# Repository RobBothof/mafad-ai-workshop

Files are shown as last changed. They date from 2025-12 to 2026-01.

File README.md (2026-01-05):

# KABK x MAFAD - AI hardware workshop

**by Rob Bothof (2026)**

---

## Synopsis

In this workshop students explore Machine Learning (ML) in a hardware-oriented context. We build insect-like robots that perform and respond to birdsong like, digital signature sounds and melodies, designed by student.

The workshop aims to debunk myths around Artificial Intelligence by focussing on fundamental / low-level neural networks that can run on a stand-alone microcontroller, free from the cloud. Students design signature sounds and create a robust dataset for neural network classification. We train and demploy the neural network model to create non-linear mappings between sensor inputs and hardware outputs.

The trained neural network model can listen to melodies of other machines in the flock. Students develop their own strategies / tactics on how their machine responds to others with the machine’s outputs (lights / speaker). By tuning and training the models on custom training data, and developing strategies for response, the end goal is to create an emergent behavioural performance from these machines as they react to each other as a group, herd, or small swarm.

---

## Subjects

- Primer on Machine Learning
- Basic soldering of electronics
- Deploy code to test sensors en outputs
- Code digital birdsong like signature sounds and melodies
- Experiment with model training and datasets
- Deploy and test a neural network model on embedded hardware
- Develop communication strategies
- Experiment and create a collaborative performance / installation

---

## Hardware Guide

[hardware/kabk_ai_workshop_hardware_guide.pdf](hardware/kabk_ai_workshop_hardware_guide.pdf)

---

## AI Primer

[primer/kabk_ai_workshop_primer.pdf](primer/kabk_ai_workshop_primer.pdf)

---

## Edge Impulse Project

[https://studio.edgeimpulse.com/public/869270/live](https://studio.edgeimpulse.com/public/869270/live)

---

## Requirements

### Hardware
- Workshop kit (PCB, electronics, UM Feather S3 board)
- Micro SD Card

### Software
- Laptop (with usb-A port)
- Arduino IDE [https://www.arduino.cc/en/software/](https://www.arduino.cc/en/software/)

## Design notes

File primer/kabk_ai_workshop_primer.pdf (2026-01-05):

Artificial Intelligence (AI)
A field and practice focused on building computational systems that perform tasks linked to human intelligence, such as recognizing patterns, creating content, or making decisions. The term is also used loosely to describe specific systems or tools that seem intelligent. Today it is most often used as a buzzword in presentations or sales pitches.

Artificial General Intelligence (AGI)
A hypothetical type of AI that could understand, learn, and perform any intellectual task a human can. Unlike current AI, which is specialized and task-specific, AGI would be flexible and adaptable across domains. Science Fiction.

Machine Learning (ML)
Machine Learning is the academic and practical discipline focused on designing systems (algorithms / models) that can ‘learn’ from data / examples and then apply that knowledge to new material.

Learning
Iterative process of automated adjustment of a system’s internal parameters, where the system’s performance is constantly monitored and influences the the adjustments for the next iteration. See also: Training (A Neural Network specific learning method)

Neural Network
A popular and powerful design architecture within Machine Learning, inspired by the structure of the human brain. It serves as the general architecture for a data model, where different types/designs of Neural Networks can perform different functions. (e.g. recognise, generate, predict). A neural network can be shallow (few layers) or deep (many layers). It is composed composed of layers of connected “neurons”

Model
The actual data structure that is being trained and used to make predictions. The term ‘model’ is easily misunderstood, we would think of a ‘model’ as being a design or a blueprint, but this term is somewhat counterintuitive. The model is a specific instance of a neural network, containing the exact layout of neurons, connections, layers and the weights (and biases) used in each neuron. A model is essentially a structured collection of numbers, comparable to a database.

Neuron
A computational unit that receives multiple input values from neurons in the previous layer and produces a single output value. Each incoming value is scaled by a weight associated with the connection it arrives on. The neuron combines these weighted inputs, applies a simple transformation, and forwards the resulting output value to connected neurons in the next layer.

Training
The process of adjusting a neural network model’s weights using a dataset of examples. Initially, all the model’s parameters (weights) are set to random values. The training process then iteratively evaluates whether changes to the weights improve or worsen how well the model matches the examples, and adjusts the weights accordingly, for example keeping, increasing, or slightly decreasing the values in preparation of the next iteration.

Loss
Measurement tool. A number used during training to show how well the model’s outputs match the examples. High loss means the model is doing poorly; lower numbers mean it’s doing better. The training process aims to reduce this number over time.

Validation
During training, the model is also tested on data it has not seen yet (similar examples, but ones are not part of the training set). This helps to determine whether the model can generalize to new data or if it has simply memorized the training examples.

Inference
Where training is very resource- and time-intensive and usually happens only once (or occasionally for updates), Inference is the common use case for a neural network model. Inference is using a model to produce an actual result. For example: classifying an image, generating text, or predicting a value. Inference is fast and lightweight compared to training.

Layer
A layer is a group of neurons in a neural network that process data together. Neural Network usually consist of multiple layers stacked on top of each other. Lower layers (closer to the input) typically capture simple features (like edges in images or individual characters or words in text), while higher layers capture more complex or abstract features (like objects such as “cat” or “face” in images, or meaning, sentiment, or topic in text). There are many different types of layers and architectures.

– Dense Layer, Fully connected layer, basic building block (weight, bias, activation function)
– CNN, Convolutional layer, local connections only, shared weights, used for images / audio
– RNN / LSTM, Recurrent layer, uses feedback, designed for sequential data (obsolete)
– Attention / Transformer, uses weighted relationships across a data-sequence, backbone modern language and audio models, used for classification and generation

– GANs, Generative Adversarial Networks, used for images generation and style transfer (obsolete) – Diffusion models, current state of the art, image, audio, and video generation, Generate data by gradually removing noise
– Autoregressive Transformers, generate data step-by-step, text, music, and audio synthesis

Weight
A weight is a number assigned to a connection between two neurons that controls how strongly the output of one neuron influences the input of the next. Weights scale incoming values before they are combined inside a neuron. During training, these weights are adjusted to strengthen useful connections and weaken unhelpful ones.

Bias
Similar to a weight, the bias is a parameter that can be changed/optimized during the training process. But where weights are stored for each connection between neurons, each neuron has their own bias value and that value is added to the sum of the values from incoming connections. It can be seen as a baseline,offset or tunable starting value for a neural. The bias gives a neural more agency or freedom to react independently from the values it receives on its inputs.
Artificial Intelligence / Machine Learning Primer ( 1 / 3 ) | version 1.0 - Rob Bothof - 2025

Activation function
An activation function is a transformation that is applied inside a neuron (after the weighted inputs and bias are combined) that shapes its output signal. It acts like a nonlinear gain or dynamics stage, controlling how strongly a neuron responds to its inputs. Neurons are not literally turned on or off; they always produce an output value, but an output close to zero is often described as the neuron being “inactive.”

Deep Learning
A subset of Machine Learning that uses ‘deep’ neural networks with many layers to learn complex patterns from data. Deep Learning models are typically more powerful than shallow networks but require more data and computational resources. It is the technique behind many modern AI applications, like image recognition and large language models.

LLM (Large Language Model)
A type of deep learning model trained on massive amounts of text to understand and generate human-like language. LLMs can perform tasks like answering questions, summarizing text, translating languages, or generating content, and rely on complex neural network architectures with billions of parameters.

Transformer
A neural network architecture designed for processing sequences of data, such as text. Transformers use mechanisms called attention to weigh the importance of different parts of the input, allowing them to capture long-range dependencies efficiently. They are the backbone of modern large language models and many state-of-the-art AI systems.

Fine-Tuning
The process of taking a pre-trained base model and continuing training on a smaller, specific dataset to adapt it to a particular task or domain. This is a popular contemporary method or creating a model. It allows one to create specialized models without the need to train an entire model from scratch.Models can be fine tunes with less cost and with simpler hardware or without the need to collect large datasets. Commonly the weights of the lower layers of a model are left locked and only the higher layers are retrained. In some cases additional layers are added on top of the base layer.

Hyperparameters
Hyperparameters are user-defined settings that control how a model is trained, not the model’s structure itself. They determine learning speed, training duration, and constraints on learning behavior. Hyperparameters are typically adjusted through experimentation and evaluated using validation data.

Classifier
A classifier is a type of AI or machine learning model that assigns an input to one of a predefined set of categories (classes) based on learned patterns in the data.

Label
A label is the class or category assigned to a data example. Labels define the set of possible outcomes a model can predict and are chosen and applied by the developer. In image/object classification, labels might include categories such as dog, cat, or bicycle.

Feature
A feature is an individual, measurable piece of information used as input to a machine learning model. Feature extraction is a preparation process to transform the data into something that is more usable in a machine learning context. Features describe characteristics of the data that the model uses to learn patterns and make predictions. For example when classifying sound, a feature is usually based on spectral content — which frequencies are present and how they change over time, not the raw audio data.

Dataset
A dataset is a structured collection of data examples used to train, tune, and evaluate an AI or machine learning model.
– Training set
Purpose: Teach the model
Used to adjust the model’s internal parameters
– Validation set
Purpose: Tune the model
Used during development to: Estimate the quality of a model, compare models, decide when to stop training. The model does not learn directly from this data – Test set
Purpose: Evaluate final performance using unseen examples of the data

Overfitting
Overfitting occurs when a model learns the training data too exact. It only memorizes the dataset exactly but is unable to generalize on characteristics and as a result performs poorly on new, unseen data. The most common causes for this are: Too little and unvaried data, the training data does not reflect real-world conditions, bad data preparation or mislabeling.
Artificial Intelligence / Machine Learning Primer ( 2 / 3 ) | version 1.0 - Rob Bothof - 2025

Artificial Intelligence / Machine Learning Primer ( 3 / 3 ) | version 1.0 - Rob Bothof - 2025

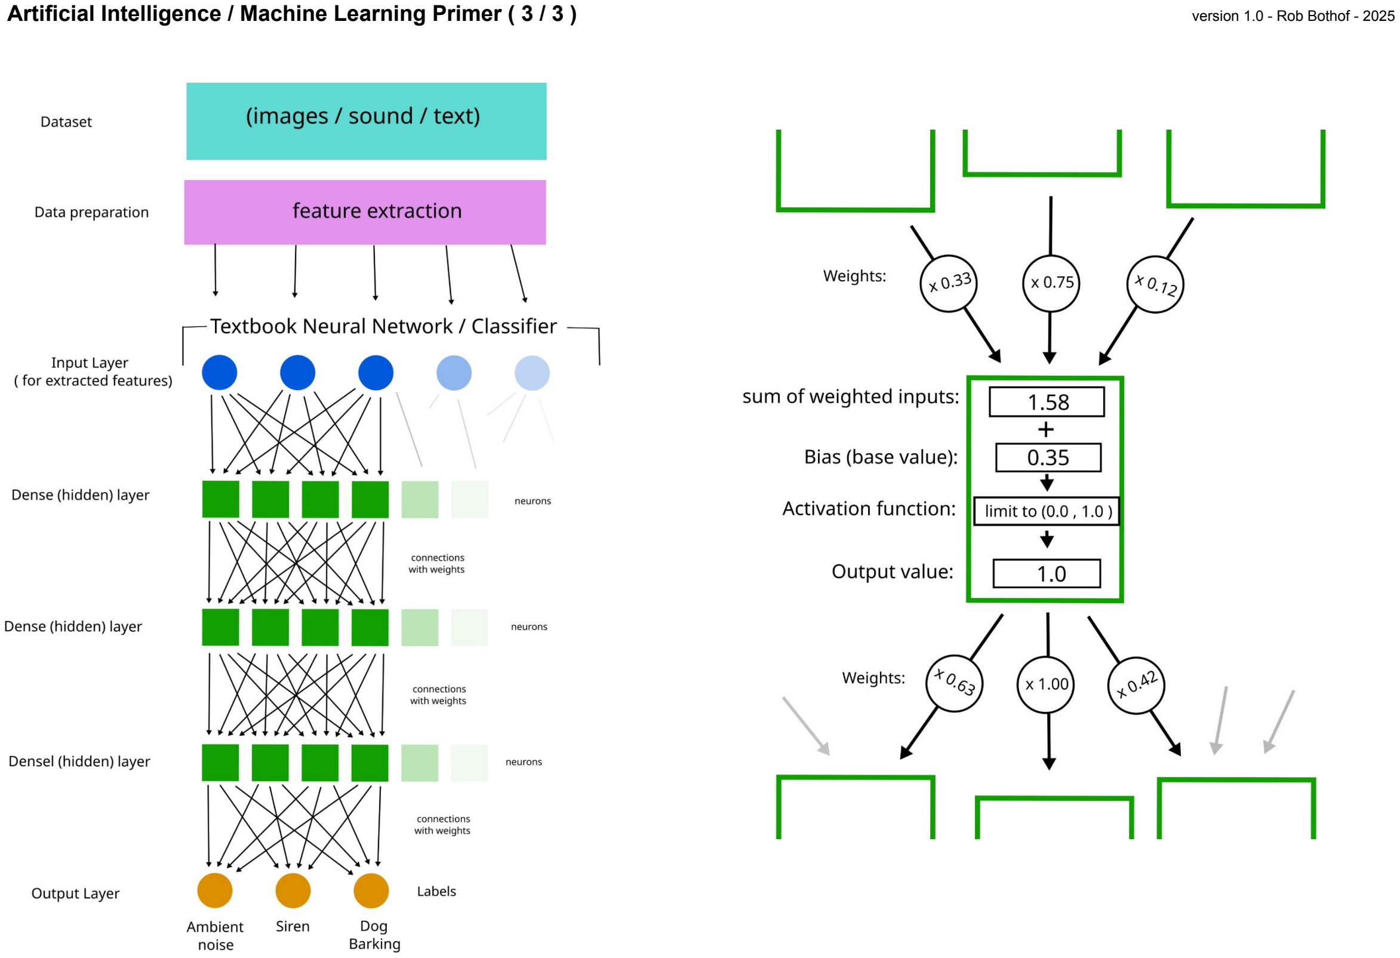
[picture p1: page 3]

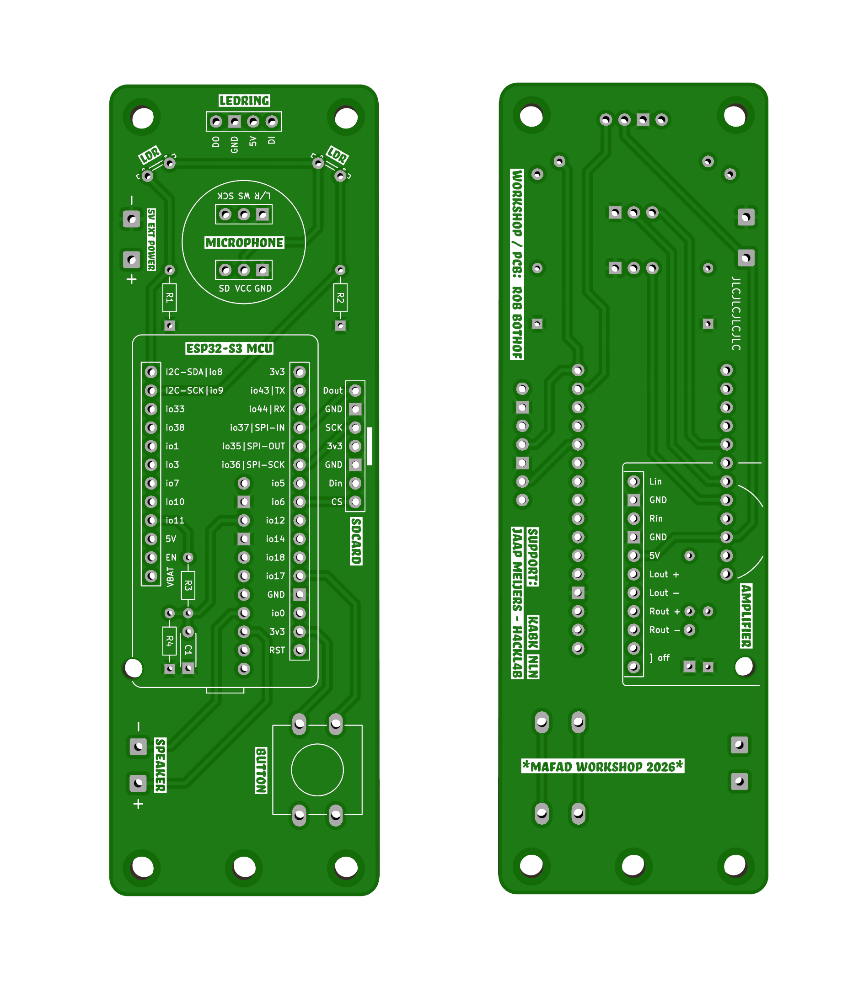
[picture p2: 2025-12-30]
hardware/PCB/MAFAD-Workshop.png

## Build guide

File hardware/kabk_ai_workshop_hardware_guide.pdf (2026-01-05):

KABK Workshop AI Hardware guide ( 1 / 1 ) | version 1.0 - Rob Bothof - 2025

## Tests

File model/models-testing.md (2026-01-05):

========================

ei-mafad-classifier-arduino-1.0.5.zip

Cropped
all classes
Window size: 1000ms
Stride: 500ms

Frame length: 0.025
Frame stride: 0.01
Filter number: 41
FFT length: 512
Low frequency: 80
High frequency: 8000
Noise floor (dB): -75

epoch: 100
learning rate: 0.05
CPU
validation size: 20%

validation:
Accuracy: 94%
Loss: 0.15

test:
Accuracy: 91.94%

hello there: ***--
ilovecake:   ***--
get bonus:   ***--
random:      ***--

distance     *----
soft-close   *----

========================

ei-mafad-classifier-arduino-1.0.8.zip

Cropped
excluded random class
Window size: 1000ms
Stride: 500ms

Frame length: 0.01
Frame stride: 0.005
Filter number: 40
FFT length: 512
Low frequency: 80
High frequency: 8000
Noise floor (dB): -50

epoch: 40
learning rate: 0.02
CPU
validation size: 20%

validation:
Accuracy: 99%
Loss: 0.04

test:
Accuracy: 99.19%

mobile performance: **---
esp32 performance:  

========================

ei-mafad-classifier-arduino-1.0.13.zip

Cropped
all classes
Window size: 1000ms
Stride: 500ms

Frame length: 0.01
Frame stride: 0.005
Filter number: 40
FFT length: 512
Low frequency: 80
High frequency: 8000
Noise floor (dB): -50

epoch: 70
learning rate: 0.02
CPU
validation size: 20%

validation:
Accuracy: 99.2%
Loss: 0.04

test:
Accuracy: 99.03%

hello there: **---
ilovecake:   ****-
get bonus:   ***--  
random:      ****-

========================

ei-mafad-classifier-arduino-1.0.22.zip
Cropped
excluded random class
Window size: 1000ms
Stride: 500ms

Frame length: 0.01
Frame stride: 0.005
Filter number: 40
FFT length: 512
Low frequency: 300
High frequency: 8000
Noise floor (dB): -65

epoch: 50
learning rate: 0.02
CPU
validation size: 20%

validation:
Accuracy: 99.0%
Loss: 0.06

test:
Accuracy: 97.58%

hello there: *----
ilovecake:   ****-
get bonus:   ***--  
random:      -----

hello there performs worse at low volume somehow

========================

ei-mafad-classifier-arduino-1.0.14.zip

Master
all classes
Window size: 1000ms
Stride: 100ms

Frame length: 0.01
Frame stride: 0.005
Filter number: 40
FFT length: 512
Low frequency: 300
High frequency: 8000
Noise floor (dB): -60

epoch: 40
learning rate: 0.02
CPU
validation size: 20%

validation:
Accuracy: 99.4%
Loss: 0.02

test:
Accuracy: 95.97%

hello there: ***__
ilovecake:   ****_
get bonus:   ****_ 
random:      ****_

========================

ei-mafad-classifier-arduino-1.0.16.zip
Master
all classes
Window size: 1000ms
Stride: 200ms

Frame length: 0.01
Frame stride: 0.005
Filter number: 40
FFT length: 512
Low frequency: 300
High frequency: 8000
Noise floor (dB): -60

epoch: 40
learning rate: 0.02
CPU
validation size: 20%

validation:
Accuracy: 98.8%
Loss: 0.06

test:
Accuracy: 93.51%

hello there: *----
ilovecake:   **---
get bonus:   -----  
random:      ***--

========================
ei-mafad-classifier-arduino-1.0.18.zip

Master
excluded random class
Window size: 1000ms
Stride: 200ms

Frame length: 0.01
Frame stride: 0.005
Filter number: 40
FFT length: 512
Low frequency: 300
High frequency: 8000
Noise floor (dB): -60

epoch: 40
learning rate: 0.02
CPU
validation size: 20%

validation:
Accuracy: 100%
Loss: 0.05

test:
Accuracy: 97.75%

mobile performance: ***--
esp32 performance:  

======================================

ei-mafad-improved-classifier-arduino-1.0.3.zip

Architecture changes

Model:

- Input layer (7,960 features)
- Reshape layer (40 columns)
- 2D conv / pool layer (8 filters, 3 kernel size, 1 layer)
- Dropout (rate 0.2)
- 2D conv / pool layer (16 filters, 3 kernel size, 1 layer)
- Flatten layer
- Output layer (4 classes)

Master
all classes
Window size: 1000ms
Stride: 200ms

Frame length: 0.01
Frame stride: 0.005
Filter number: 40
FFT length: 512
Low frequency: 300
High frequency: 8000
Noise floor (dB): -65

epoch: 14
learning rate: 0.02
CPU
validation size: 20%

validation:
Accuracy: 99.2%
Loss: 0.05

test:
Accuracy: 94.56%

hello there: **---
get bonus:   ***--  
ilovecake:   ***--
random:      ****-

======================================

BEST MODEL:

ei-mafad-improved-classifier-arduino-1.0.5

Architecture changes

Model:

- Input layer (7,960 features)
- Reshape layer (40 columns)
- 2D conv / pool layer (6 filters, 5 kernel size, 1 layer)
- Dropout (rate 0.2)
- 2D conv / pool layer (12 filters, 3 kernel size, 1 layer)
- Flatten layer
- Output layer (4 classes)

Master
no random class
Window size: 1000ms
Stride: 200ms

Frame length: 0.01
Frame stride: 0.005
Filter number: 40
FFT length: 512
Low frequency: 300
High frequency: 8000
Noise floor (dB): -65

epoch: 15
learning rate: 0.02
CPU
validation size: 20%

validation:
Accuracy: 99.0%
Loss: 0.05

test:
Accuracy: 97.72%

hello there:    ****-
get bonus:      ****-    
ilovecake:      ***--
random:         -----

softer sounds  ****_
long distance   ***__
======================================

ei-mafad-improved-classifier-arduino-1.0.7
Architecture changes

Model:

- Input layer (7,960 features)
- Reshape layer (40 columns)
- 2D conv / pool layer (6 filters, 5 kernel size, 1 layer)
- Dropout (rate 0.2)
- 2D conv / pool layer (12 filters, 3 kernel size, 1 layer)
- Flatten layer
- Output layer (4 classes)

Master
all classes
Window size: 1000ms
Stride: 50ms

Frame length: 0.01
Frame stride: 0.005
Filter number: 40
FFT length: 256
Low frequency: 300
High frequency: 8000
Noise floor (dB): -40

epoch: 10
learning rate: 0.02
CPU
validation size: 20%

validation:
Accuracy: 98.4%
Loss: 0.06

test:
Accuracy: 98.41%

hello there: **---
ilovecake:   ***--
get bonus:   ****-    
random:      ****-

softer sounds **---
long distance **---

============================================================================
ei-mafad-improved-classifier-arduino-1.0.9.zip

Architecture changes

Model:

- Input layer (7,960 features)
- Reshape layer (40 columns)
- 2D conv / pool layer (6 filters, 5 kernel size, 1 layer)
- Dropout (rate 0.2)
- 2D conv / pool layer (12 filters, 3 kernel size, 1 layer)
- Flatten layer
- Output layer (4 classes)

Manual Crops
all classes
Window size: 1000ms
Stride: 200ms

Frame length: 0.02
Frame stride: 0.015
Filter number: 30
FFT length: 128
Low frequency: 300
High frequency: 8000
Noise floor (dB): -40

epoch: 20
learning rate: 0.02
CPU
validation size: 20%

validation:
Accuracy: 94.55%
Loss: 0.15

test:
Accuracy: 94.55%

hello there: ***--
ilovecake:   ***--
get bonus:   *----
random:      ****-

======================================
======================================

======================================
======================================
======================================
======================================
New dataset (but hello_there only had 1/2 samples)
======================================
ei-mafad-classifier-arduino-1.0.23.zip

Model:

- Input layer (7,960 features)
- Reshape layer (40 columns)
- 2D conv / pool layer (8 filters, 5 kernel size, 1 layer)
- Dropout (rate 0.2)
- 2D conv / pool layer (16 filters, 3 kernel size, 1 layer)
- Flatten layer
- Output layer (4 classes)

Master Files
all classews
Window size: 1000ms
Stride: 200ms

Frame length: 0.01
Frame stride: 0.005
Filter number: 40
FFT length: 512
Low frequency: 200
High frequency: 7000
Noise floor (dB): -75

epoch: 15
learning rate: 0.02
CPU
validation size: 20%

validation:
Accuracy: 85.3%
for melody labels: 100%
Loss: 0.4

test:
Accuracy: 76.96%
for melody labels: 98%

hello there: -----
ilovecake:   -----
get bonus:   -----
random:      -----

=====================================
======================================
ei-mafad-classifier-arduino-1.0.25.zip

Model:

- Input layer (7,960 features)
- Reshape layer (40 columns)
- 2D conv / pool layer (8 filters, 5 kernel size, 1 layer)
- Dropout (rate 0.2)
- 2D conv / pool layer (16 filters, 3 kernel size, 1 layer)
- Flatten layer
- Output layer (4 classes)

Master Files
(noise + random combined)
Window size: 1000ms
Stride: 200ms

Frame length: 0.01
Frame stride: 0.005
Filter number: 40
FFT length: 512
Low frequency: 200
High frequency: 7000
Noise floor (dB): -75

epoch: 15
learning rate: 0.02
CPU
validation size: 20%

validation:
Accuracy: 97.2%
Loss: 0.07

test:
Accuracy: 95.49%

hello there: ***--
ilovecake:   *****
get bonus:   *****
noise:       *****

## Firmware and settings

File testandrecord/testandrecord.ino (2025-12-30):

#include <Bounce2.h>
#include "workshop/WS2812.h"
#include "workshop/workshop_library.h"
#include "workshop/pitches.h"

#define I2S_MIC_SCK_PIN 1         // clockPin
#define I2S_MIC_WS_PIN 7          // wordSelectPin
#define I2S_MIC_SD_PIN 10         // channelSelectPin

#define SDCARD_CS_PIN 6           // sdcard chip select pin

#define AUDIO_OUT_PIN 11          // amplifier / speaker pin
#define BUTTON_PIN 17             // button pin
#define LEDRING_PIN 43            // ledring data pin

#define LDR_LEFT_PIN 8            // left lightsensor pin
#define LDR_RIGHT_PIN 9           // right lightsensor pin

#define SAMPLE_RATE 20000         // recording quality 20khz (20.000 samples per second)
#define SAMPLE_BUFFER_SIZE 40000  // size of the audio buffer, 2 seconds ( 2 * 20.000 = 40000 samples)

#define NUM_LEDS 8                // the ledring uses 8 leds


// Create an array/list to store 8 colors for the ledring.
Color leds[NUM_LEDS];       
int activeLed = 0;

// Create a button object (with debouncing).
Bounce2::Button Button1 = Bounce2::Button();

// Create a led ring object.
WS2812 ledRing;

// Create a sd card object.
SDCard sdCard;

// Create a microphone object.
i2sMic microphone;

// Define a series of notes. (Cminor chord)
int melody[] = { NOTE_C3, NOTE_D3, NOTE_DS3, NOTE_F3, NOTE_G3, NOTE_GS3, NOTE_AS3, NOTE_C4};

// Create a 32bits buffer to store audio.
int32_t audioBuffer[SAMPLE_BUFFER_SIZE]; 

// Create a boolean to remember if an sd card is present.
bool hasSDCard = false;

// Create a value to keep track of elapsed time.
unsigned long log_timer=0;

// Create a value to keep track of the recordings we store
unsigned int fileIndex=0;

// Create a series of notes.
int notes[] = {
  NOTE_C2, NOTE_CS2, NOTE_D2, NOTE_DS2, NOTE_E2, NOTE_F2, NOTE_FS2, NOTE_G2, NOTE_GS2, NOTE_A2, NOTE_AS2, NOTE_B2,
  NOTE_C3, NOTE_CS3, NOTE_D3, NOTE_DS3, NOTE_E3, NOTE_F3, NOTE_FS3, NOTE_G3, NOTE_GS3, NOTE_A3, NOTE_AS3, NOTE_B3,
  NOTE_C4, NOTE_CS4, NOTE_D4, NOTE_DS4, NOTE_E4, NOTE_F4, NOTE_FS4, NOTE_G4, NOTE_GS4, NOTE_A4, NOTE_AS4, NOTE_B4,
  NOTE_C5, NOTE_CS5, NOTE_D5, NOTE_DS5, NOTE_E5, NOTE_F5, NOTE_FS5, NOTE_G5, NOTE_GS5, NOTE_A5, NOTE_AS5, NOTE_B5,
  NOTE_C6
};




void setup(){

  // Setup LightSensors
  pinMode(LDR_LEFT_PIN,INPUT);
  pinMode(LDR_RIGHT_PIN,INPUT);

  // Setup LedRing
  pinMode(LEDRING_PIN, OUTPUT);
  ledRing.init(LEDRING_PIN, leds, NUM_LEDS);

  // Turn all leds off
  for (int l=0; l < NUM_LEDS; l++) {
    leds[l].hex = 0x000000;
  }
  ledRing.update();

  // Setup microphone
  microphone.setup(SAMPLE_RATE, I2S_MIC_SCK_PIN, I2S_MIC_WS_PIN, I2S_MIC_SD_PIN);

  // Setup printing to serial monitor
  Serial.begin(115200);
  Serial.println("\n--------------------");

  // Set up Button
  Button1.attach(BUTTON_PIN, INPUT_PULLDOWN);
  // Set debounce time
  Button1.interval(10);
  Button1.setPressedState(HIGH); 

  // Setup audio output
  pinMode(AUDIO_OUT_PIN, OUTPUT);
  analogWriteResolution(AUDIO_OUT_PIN, 10);

  // Try to mount the SD Card and remember if it is present
  hasSDCard = sdCard.setup(SDCARD_CS_PIN);

  delay(1000);

  // Play 8 notes and light up 8 LEDs
  for (int index = 0; index < 8; index++) {

    // Set the LED corressponding with to a random color (random Hue)
    leds[index] = Color::FromHSL(random(255),255,128);
    // Write the led values to the ledRing.
    ledRing.update();

    // set the corresponding frequency of the note.
    analogWriteFrequency(AUDIO_OUT_PIN, melody[index]);

    // Sound on.
    analogWrite(AUDIO_OUT_PIN, 512);

    // Wait 1/2 second.
    delay(500);

    // Sound on.
    analogWrite(AUDIO_OUT_PIN, 0);

    // Set all leds to off
    for (int l = 0; l < NUM_LEDS; l++) {
      leds[l].hex = 0x000000;
    }
    // Write the led values to the ledRing.
    ledRing.update();

    // Wait 1/5 seconds.
    delay(200);

  }

  Serial.println();
  Serial.println("Press button to record a test sample");
  Serial.println();

  // prime the timer (set it to current time)
  log_timer = millis();
}

void loop(){
  Button1.update();

  if(Button1.pressed()) {  // Returns true if the button was pressed

      // wait 1/5 of a second before starting with recording
      delay(200); 
      Serial.println("Now recording 2 seconds..");

      int numSamplesRecorded = microphone.record(audioBuffer, SAMPLE_BUFFER_SIZE);
  
      Serial.print("samples recorded:");
      Serial.println(numSamplesRecorded);
      Serial.println();

      // save the recorded audio to the SDCard (if present)
      if (hasSDCard) {
        // Create a filename with the format: /recording_0001.wav 
        String filename = sdCard.makeFilename("/recording", fileIndex);

        // Increase the file index with 1
        fileIndex++;

        Serial.print("Saving on SDCard as:");
        Serial.println(filename);
        Serial.println();

        sdCard.writeWavFile(filename, audioBuffer, numSamplesRecorded, SAMPLE_RATE);
      }      
  } 

  // Print the values of the lightsensors every second.
  // this prevents the values being logged continuously, stalling the device
  if (millis() > log_timer + 1000) {
    // set our timer to the current time.
    log_timer = millis();
    Serial.print("Light Sensor L:");
    Serial.print(analogRead(LDR_LEFT_PIN));
    Serial.print(" | Light Sensor R:");
    Serial.println(analogRead(LDR_RIGHT_PIN));
  }


}

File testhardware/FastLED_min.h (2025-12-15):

/*
 * WS2812_ARRAY - WS2812B Library for ESP32S3 (CORE >= v3) using RMT
 * 
 * Supports: WS2812B, WS2812, WS2811 compatible LEDs
 *
 * Rob Bothof [rbothof@xs4all.nl]
 */

#ifndef WS2812_ARRAY
#define WS2812_ARRAY

#include <Arduino.h>

class Color {
public:
  union {
    struct {
      uint8_t b;
      uint8_t r;
      uint8_t g;
      uint8_t x; // 8 bit spacer so we can map hex values like 0xFF00FF to r,g,b
    };
    uint32_t hex;
  };
  
  // Constructors
  Color() : r(0), g(0), b(0) {}
  Color(uint8_t red, uint8_t green, uint8_t blue) : x(0), r(red), g(green), b(blue) {}
  Color(uint32_t rawvalue) : hex(rawvalue) {}
  
  // Named colors
  static const Color Black;
  static const Color Red;
  static const Color Green;
  static const Color Blue;
  static const Color Yellow;
  static const Color Cyan;
  static const Color Magenta;
  static const Color White;
  static const Color Orange;
  static const Color Purple;
  static const Color Pink;
  
  // Copy Operator
  Color& operator=(const Color& other) {
    x = 0;
    r = other.r;
    g = other.g;
    b = other.b;
    return *this;
  }
};

// Define named colors
inline const Color Color::Black = Color(0, 0, 0);
inline const Color Color::Red = Color(255, 0, 0);
inline const Color Color::Green = Color(0, 255, 0);
inline const Color Color::Blue = Color(0, 0, 255);
inline const Color Color::Yellow = Color(255, 255, 0);
inline const Color Color::Cyan = Color(0, 255, 255);
inline const Color Color::Magenta = Color(255, 0, 255);
inline const Color Color::White = Color(255, 255, 255);
inline const Color Color::Orange = Color(255, 165, 0);
inline const Color Color::Purple = Color(128, 0, 128);
inline const Color Color::Pink = Color(255, 192, 203);

class WS2812Array {
private:
  Color* leds;
  uint16_t numLeds;
  bool initialized;
  uint8_t pin;
  
public:
  WS2812Array() : pin(0), leds(nullptr), numLeds(0), initialized(false) {}
  
  void init(uint8_t datapin, Color* ledArray, uint16_t count) {
    pin = datapin;
    leds = ledArray;
    numLeds = count;
    #if SOC_RMT_SUPPORTED

    if (!rmtInit(pin, RMT_TX_MODE, RMT_MEM_NUM_BLOCKS_1, 10000000)) {
      Serial.println("RMT initialization failed!");
      return;
    }
    initialized=true;
    #endif
  }
  
  void update() {
    if (!initialized || leds == nullptr) return;
    
    #if SOC_RMT_SUPPORTED
  
    rmt_data_t led_data[24*numLeds];
    int led_data_index = 0;
    uint8_t led_data_value=0;

    for (uint16_t l = 0; l < numLeds; l++) {
      for (int c = 0; c < 3; c++) {
        for (int bit = 0; bit < 8; bit++) {
          if (c==0) led_data_value = leds[l].r;
          if (c==1) led_data_value = leds[l].g;
          if (c==2) led_data_value = leds[l].b;

          if (led_data_value & (1 << (7 - bit))) {
            led_data[led_data_index].level0 = 1; // HIGH bit
            led_data[led_data_index].duration0 = 8; // 0.8us
            led_data[led_data_index].level1 = 0; // LOW bit
            led_data[led_data_index].duration1 = 4; // 0.4us
          } else {
            led_data[led_data_index].level0 = 1; // LOW bit
            led_data[led_data_index].duration0 = 4; // 0.4us
            led_data[led_data_index].level1 = 0; // HIGH bit
            led_data[led_data_index].duration1 = 8; // 0.8us
          }
          led_data_index++;
        }
      }
    }

    // Write the data to the LEDRING
    rmtWrite(pin, led_data, RMT_SYMBOLS_OF(led_data), RMT_WAIT_FOR_EVER);

    #else
    Serial.println("RMT is not supported on this target.");
    #endif
  }
  
  void clear() {
    if (leds == nullptr) return;
    for (uint16_t i = 0; i < numLeds; i++) {
      leds[i].hex=0x000000;
    }
  }
  
  Color& operator[](uint16_t index) {
    return leds[index];
  }
};


#endif // WS2812_ARRAY

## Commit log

2025-12-30 added kicad pcb layout
    [MAFAD-Workshop.kicad_pcb]
2026-01-06 scanning ledring during inference
2026-01-06 added zipped library to install in arduino IDE
